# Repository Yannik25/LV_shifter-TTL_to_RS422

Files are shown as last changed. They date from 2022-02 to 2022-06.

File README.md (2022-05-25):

# LV_shifter-TTL_to_RS422

Top view:<br />
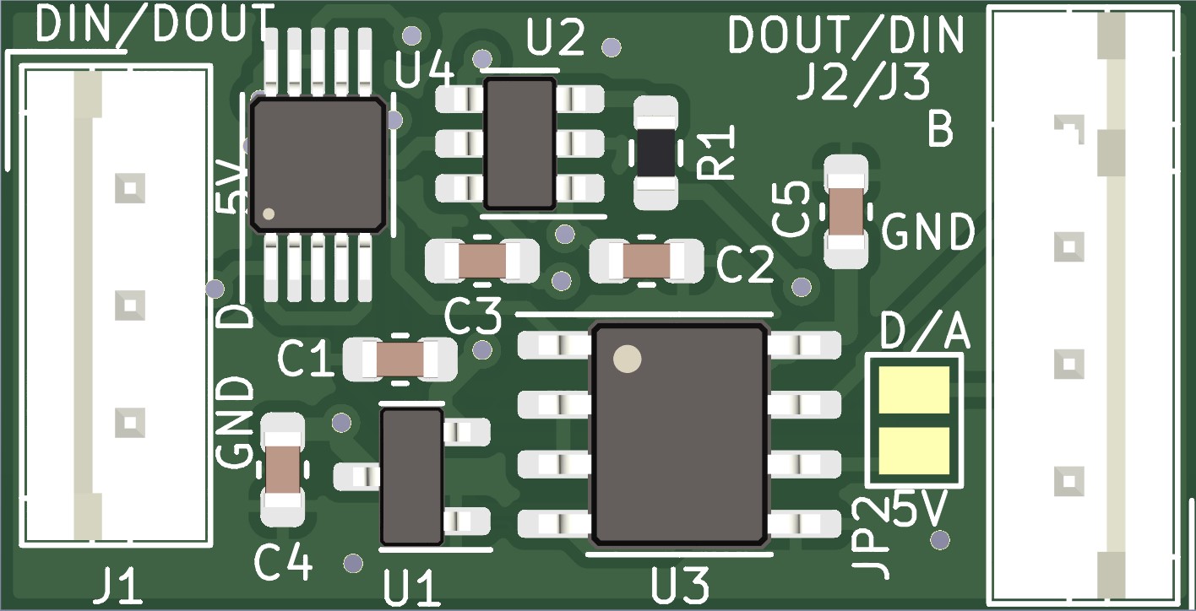
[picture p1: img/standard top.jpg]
<br />
Bottom view:<br />
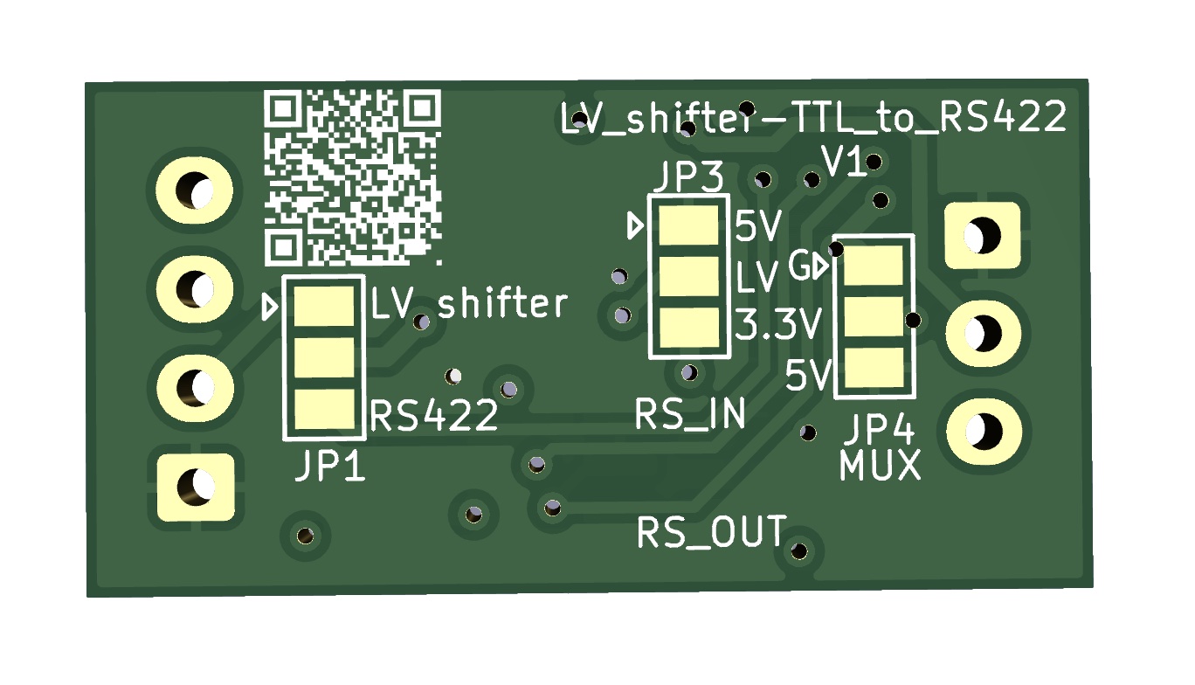
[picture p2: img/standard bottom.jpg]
<br />
## Configuration

### Simple 3.3V to 5V Levelshifter:
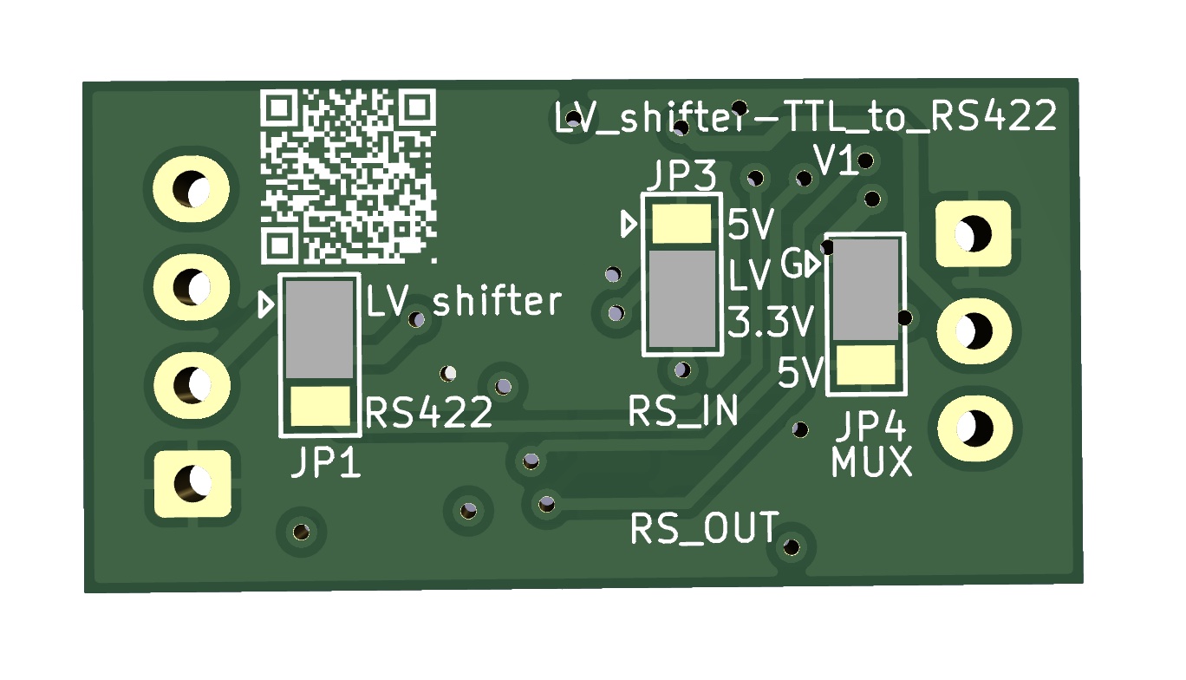
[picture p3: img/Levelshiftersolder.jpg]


### Digital LED over long cable with RS422:
Sender: From ESP (3.3V pin) -> Levelshift to 5V -> Translate to RS422 -> send out.<br />
Receiver: receive RS422 -> translate back -> control 5V digital LED.

Sender solder config       |  Receiver solder config
:-------------------------:|:-------------------------:
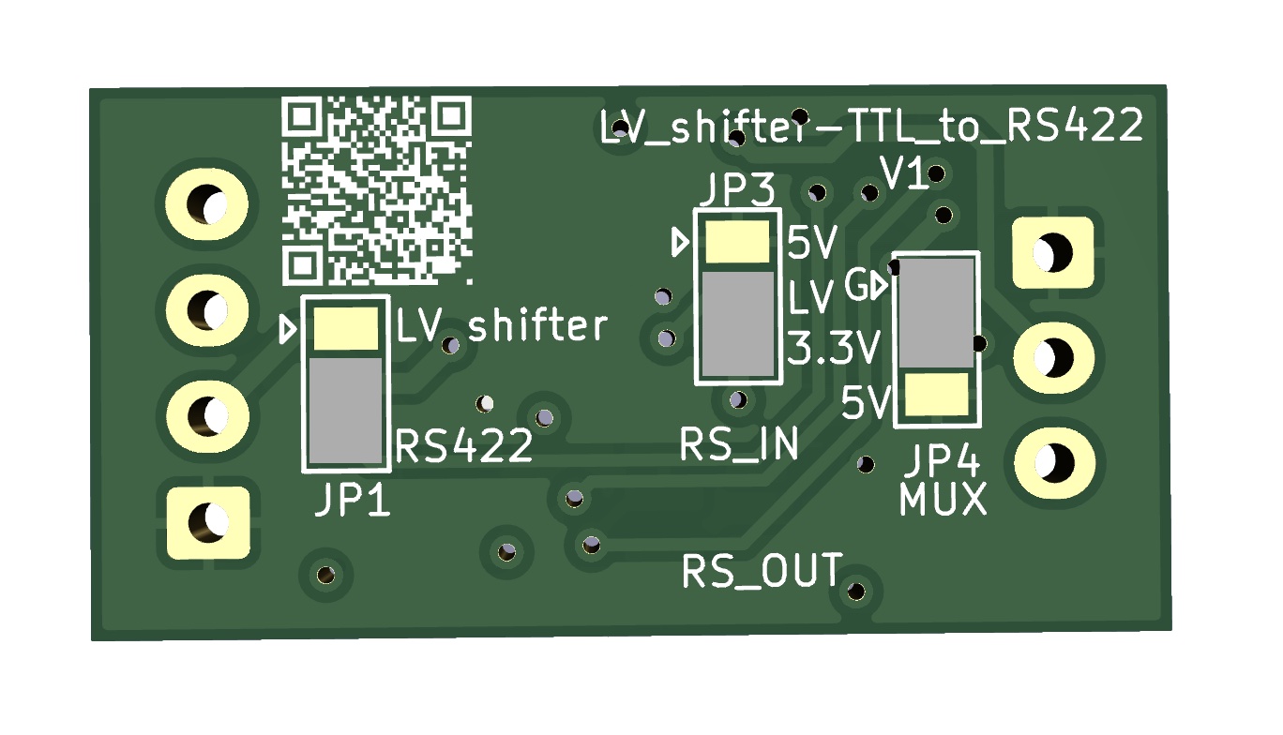
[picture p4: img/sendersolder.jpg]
Sender solder config
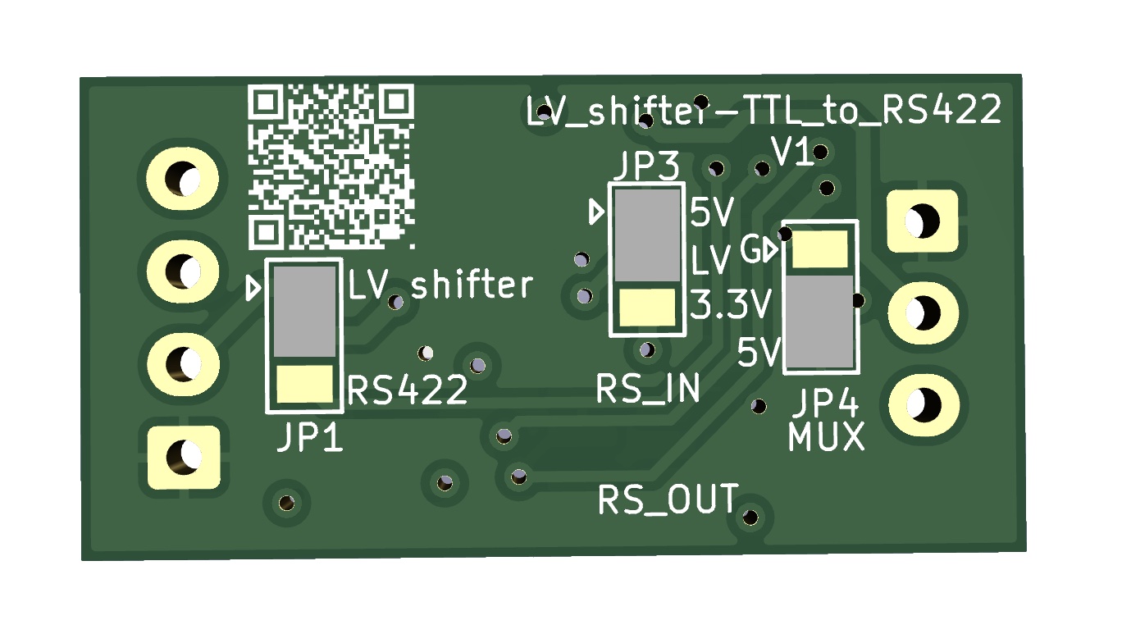
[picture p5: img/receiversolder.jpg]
Receiver solder config
   |

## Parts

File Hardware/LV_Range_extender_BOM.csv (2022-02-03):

Comment | Designator | Footprint | LCSC
0.1uF | C1 C2 C3 C4 C5 | Capacitor_SMD:C_0603_1608Metric
150 | R1 | Resistor_SMD:R_0603_1608Metric
ME6211A33M3G-N | U1 | Package_TO_SOT_SMD:SOT-23
SN74LVC1T45DBV | U2 | Package_TO_SOT_SMD:SOT-23-6
SN75176AD | U3 | Package_SO:SOIC-8_3.9x4.9mm_P1.27mm
TS5A23159DGS | U4 | Package_SO:VSSOP-10_3x3mm_P0.5mm

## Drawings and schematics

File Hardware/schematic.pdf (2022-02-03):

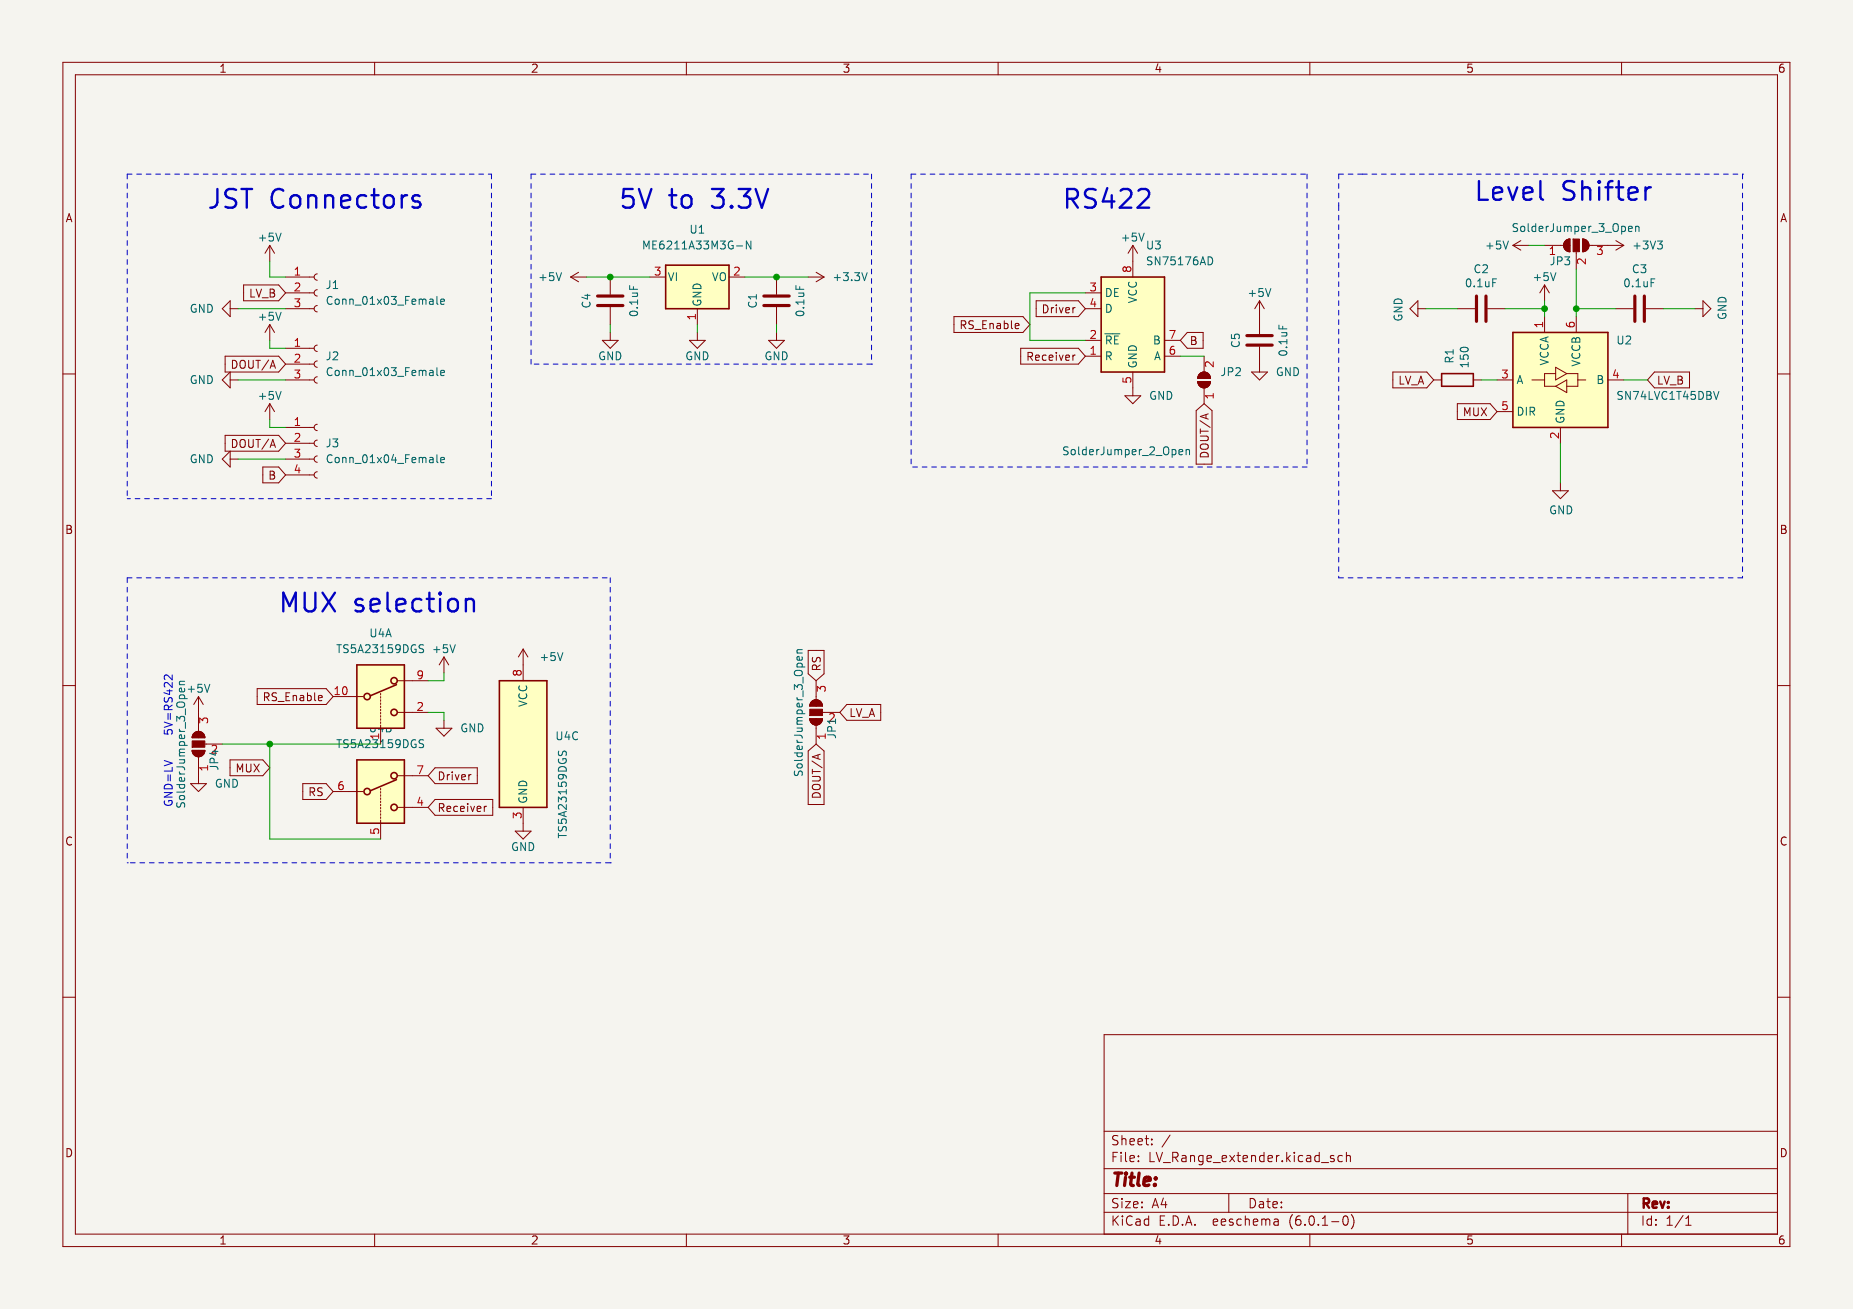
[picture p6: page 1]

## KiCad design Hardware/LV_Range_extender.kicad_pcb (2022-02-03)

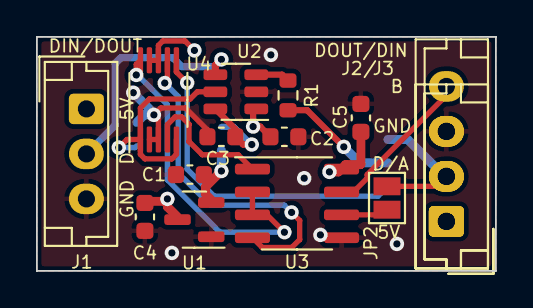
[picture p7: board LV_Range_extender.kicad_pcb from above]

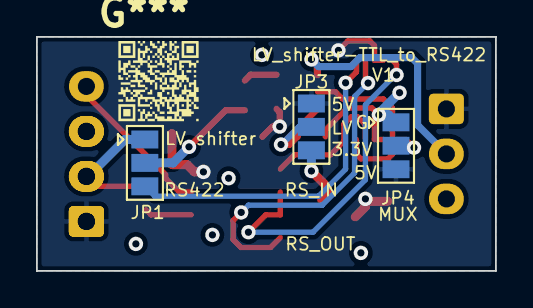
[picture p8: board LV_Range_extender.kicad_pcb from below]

Board: 2 copper layers, 25.5 x 13.0 mm, 17 parts (3 on the bottom side), 15 nets.

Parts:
C1, C2, C3, C4, C5: 0.1uF; C_0603_1608Metric
J1, J2: Conn_01x03_Female; JST_EH_B3B-EH-A_1x03_P2.50mm_Vertical
J3: Conn_01x04_Female; JST_EH_B4B-EH-A_1x04_P2.50mm_Vertical
JP1, JP3, JP4: SolderJumper_3_Open; SolderJumper-3_P1.3mm_Open_Pad1.0x1.5mm
JP2: SolderJumper_2_Open; SolderJumper-2_P1.3mm_Open_Pad1.0x1.5mm
R1: 150; R_0603_1608Metric
U1: ME6211A33M3G-N; SOT-23
U2: SN74LVC1T45DBV; SOT-23-6
U3: SN75176AD; SOIC-8_3.9x4.9mm_P1.27mm
U4: TS5A23159DGS; VSSOP-10_3x3mm_P0.5mm

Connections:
+3V3: C1.2, JP3.3 (B), U1.2 (VO)
+5V: C2.1, C4.2, C5.2, J1.1, J2.1, J3.1, JP3.1 (A), JP4.3 (B), U1.3 (VI), U2.1 (VCCA), U3.8 (VCC), U4.8 (VCC), U4.9
B: J3.4, U3.7 (B)
DOUT/A: J2.2, J3.2, JP1.1 (A), JP2.1 (A)
Driver: U3.4 (D), U4.7
GND: C1.1, C2.2, C3.1, C4.1, C5.1, J1.3, J2.3, J3.3, JP4.1 (A), U1.1 (GND), U2.2 (GND), U3.5 (GND), U4.2, U4.3 (GND)
LV_A: JP1.2 (C), R1.1
LV_B: J1.2, U2.4 (B)
MUX: JP4.2 (C), U2.5 (DIR), U4.1, U4.5
unnamed: C3.2, JP3.2 (C), U2.6 (VCCB)
unnamed: R1.2, U2.3 (A)
unnamed: JP2.2 (B), U3.6 (A)
RS: JP1.3 (B), U4.6
RS_Enable: U3.2 (~RE), U3.3 (DE), U4.10
Receiver: U3.1 (R), U4.4

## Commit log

2022-02-01 initial Release
    [LV_Range_extender.kicad_pcb, LV_Range_extender.kicad_sch]
2022-02-01 add multiplexer
    [LV_Range_extender.kicad_pcb, LV_Range_extender.kicad_sch]
2022-02-02 update multiplexing
    [LV_Range_extender.kicad_pcb, LV_Range_extender.kicad_sch]
2022-02-03 Add ordered version V1
    [LV_Range_extender.kicad_pcb, LV_Range_extender.kicad_sch, LV_Range_extender_BOM.csv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]
2022-05-25 add images for solder config
2024-12-25 Update LV_Range_extender-top-pos.csv
    Correct placement orientation of ICs
    [LV_Range_extender-top-pos.csv]
